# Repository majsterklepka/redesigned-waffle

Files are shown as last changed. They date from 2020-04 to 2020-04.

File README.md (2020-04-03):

# redesigned-waffle
mkII AVRISP programmer clone

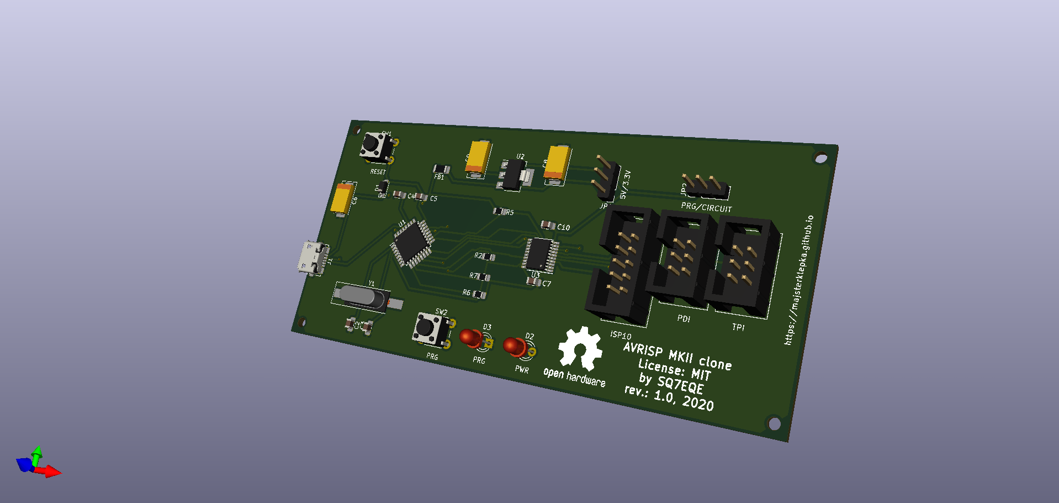
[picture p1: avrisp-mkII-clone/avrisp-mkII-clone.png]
PCB 3D view PCB Board 3D view


Projekt klonu wykonany w KiCad. Pewne elementy schematu ideowego wymagają bibliotek, są one dostępne tu: [majsterklepka/expert-waffle](https://github.com/majsterklepka/expert-waffle "eeschema KiCad Libraries"), należy sklonować repo i zainstalować wymagane biblioteki ręcznie.

Klon wykorzystuje framework [LUFA](https://github.com/abcminiuser/lufa "LUFA")

Schemat ideowy => [diagram](/avrisp-mkII-clone/avrisp-mkII-clone.pdf "diagram")

> **2020.04.02**   Dodałem pliki Gerber z rysunkiem płytki drukowanej

## Jak wgrać firmware?

Oczywiście, najpier należy je zdbudować, potem do wgrania firmware wykorzystuje się narzędzie `dfu-util` dostępne chyba w każdej dystrybucji Linuksa i xxxBSD.

## Jak wgrać firmware?

```
dfu-util --upload firmware.hex

gdzie:
firmware.hex - plik HEX z firmware, LUFA/Projects/AVRISP-MKII/

```

Tyle w skrócie, czasem należy podać dodatkowe dane, takie jak `<vendor>:<product>`. Te dane podaje się z opcją `--device`, więcej informacji:

```
dfu-util --help
```

## Credits

Jako taki projekt jest znany w Sieci, istnieje wiele dostępnych modyfikacji, tu jest jedna z nich.

- [MIT](https://raw.githubusercontent.com/majsterklepka/redesigned-waffle/master/LICENSE "MIT License content")

Ten projekt to moja wersja, moja wizja tego popularnego programatora.

_MSc. Paweł Sobótka (SQ7EQE)_

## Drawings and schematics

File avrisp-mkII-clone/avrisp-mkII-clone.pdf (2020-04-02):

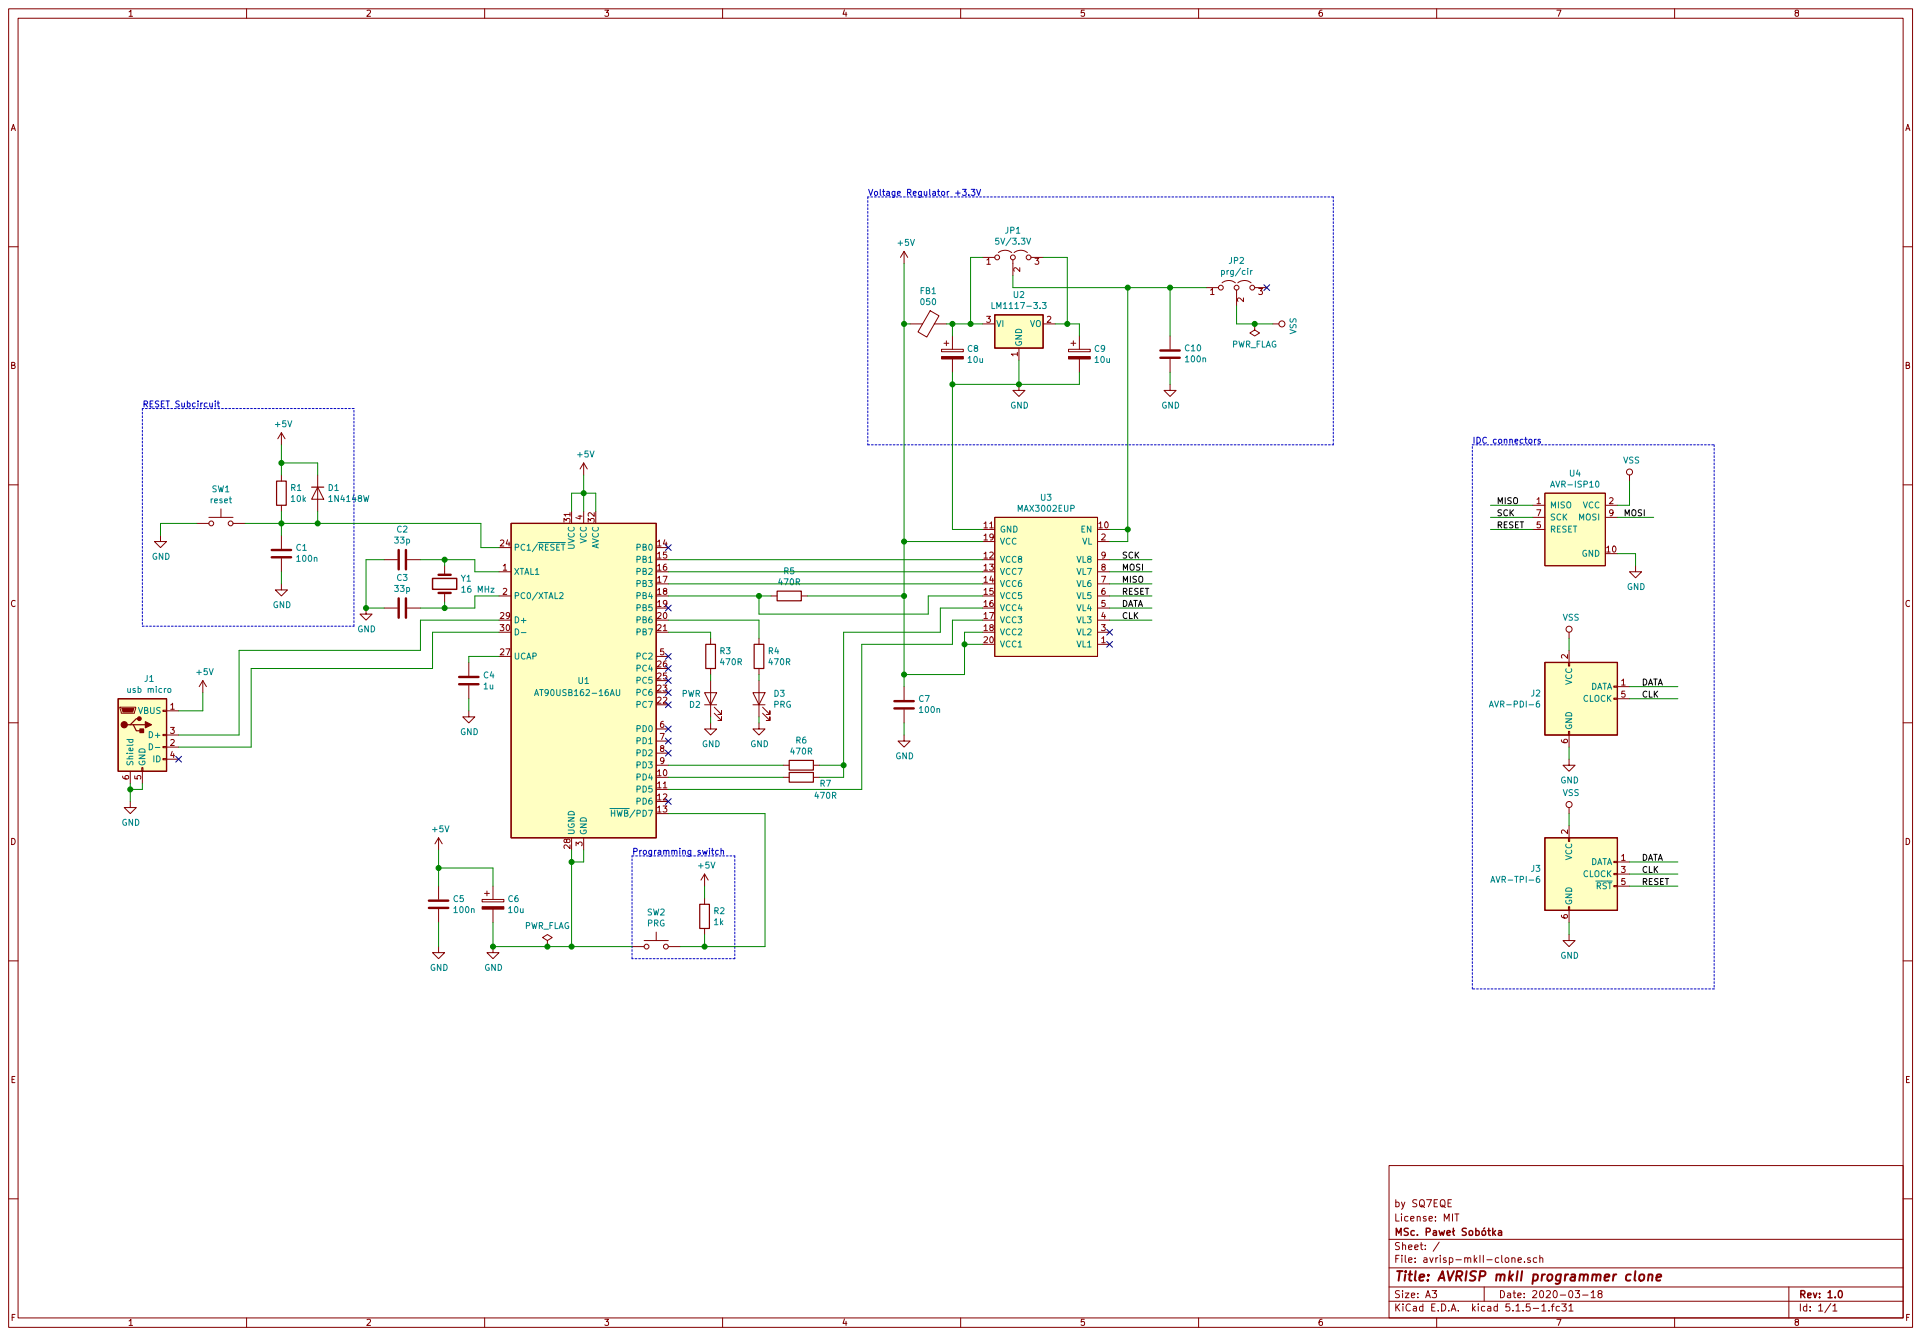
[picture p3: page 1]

IDC connectors Programming switch

by SQ7EQE
License: MIT
File: avrisp-mkII-clone.sch Sheet: / MSc. Pawe Sobótka

Id: 1/1 Title: AVRISP mkII programmer clone

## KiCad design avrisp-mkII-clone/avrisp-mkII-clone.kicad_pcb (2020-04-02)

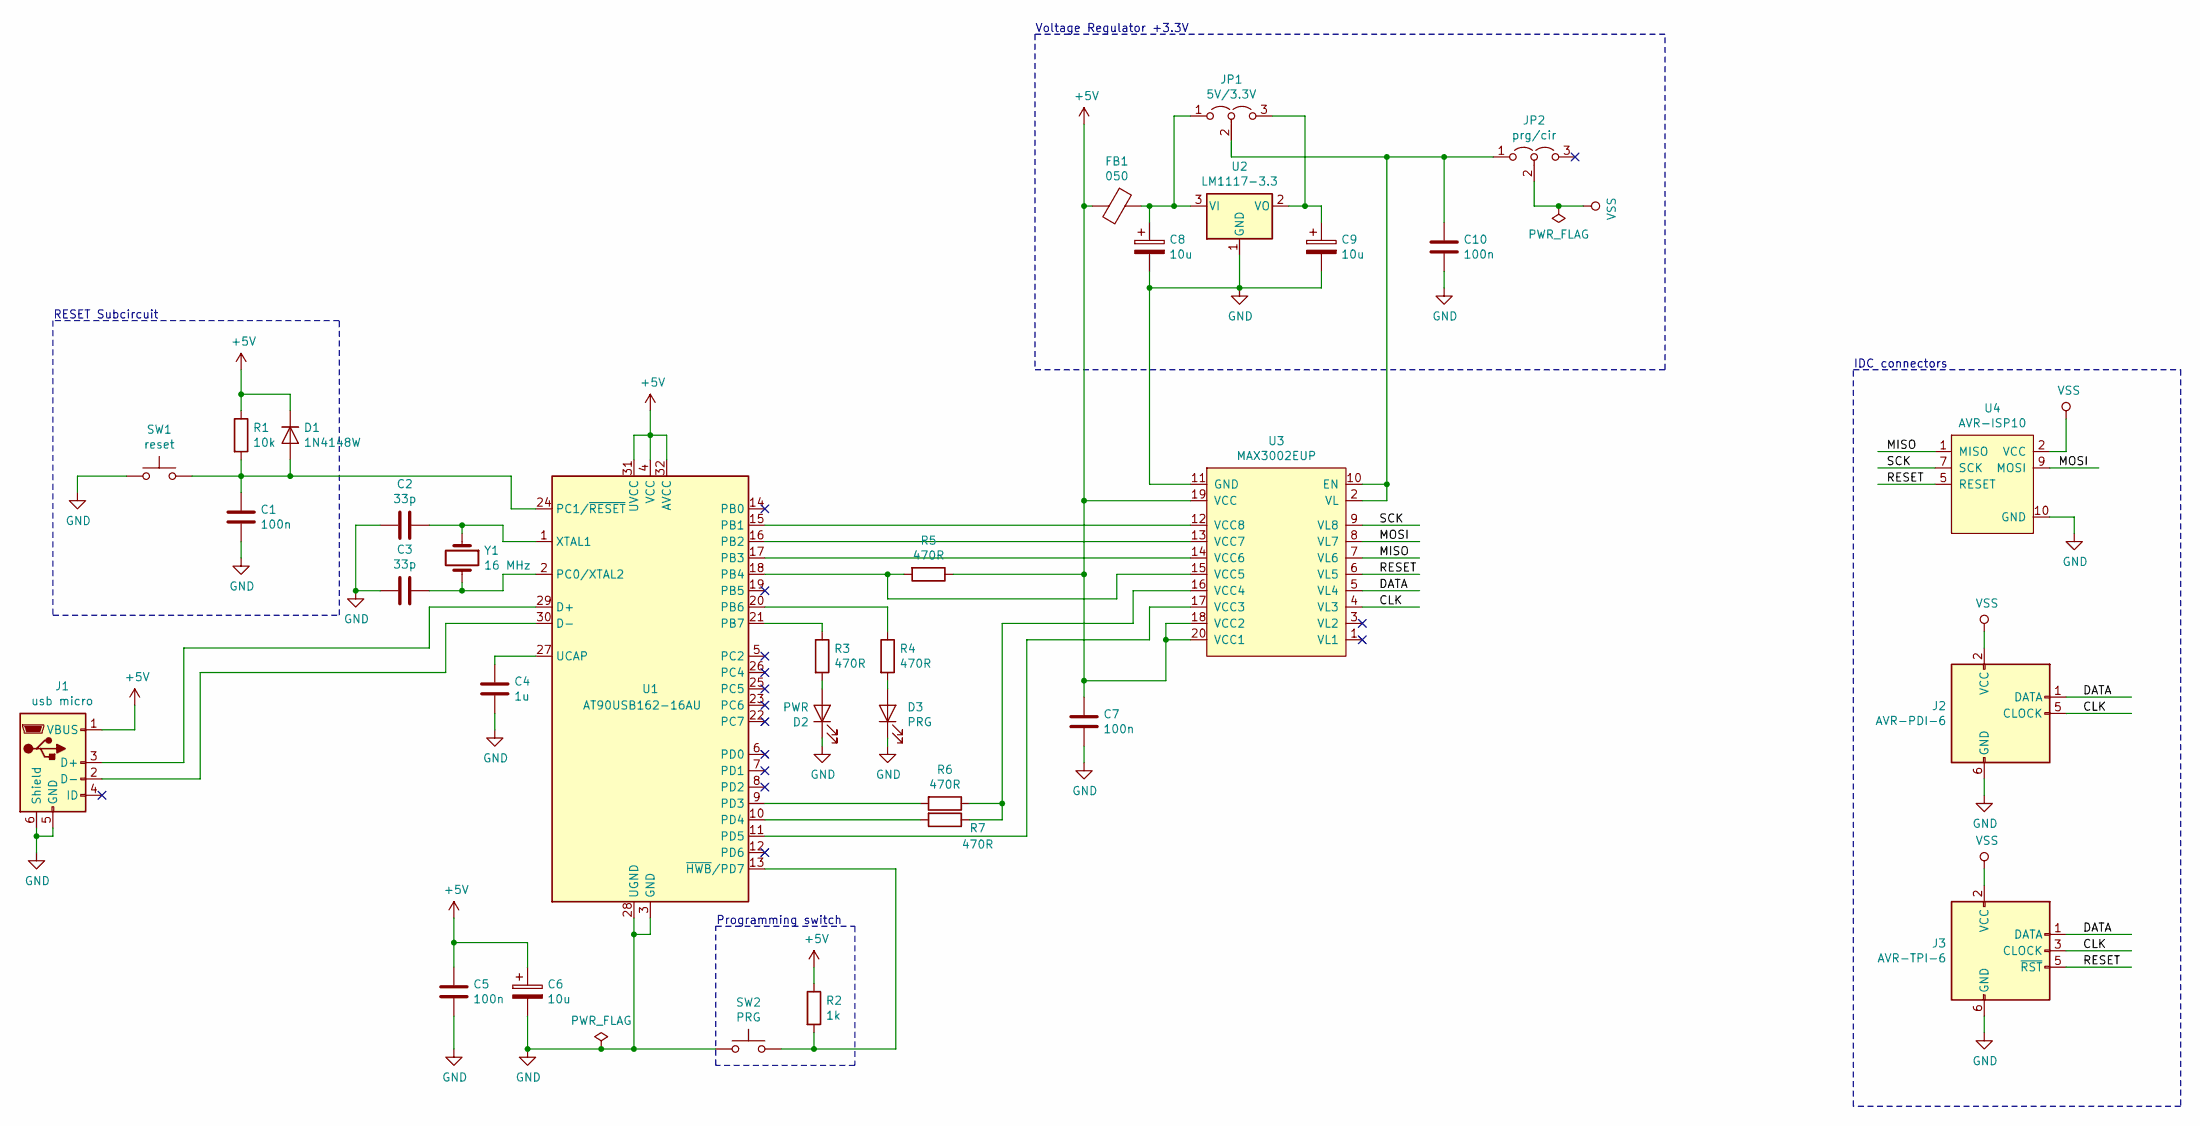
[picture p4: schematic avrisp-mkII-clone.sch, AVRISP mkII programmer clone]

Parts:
C1, C5, C7, C10: 100n; C_0805_2012Metric_Pad1.15x1.40mm_HandSolder
C2, C3: 33p; C_0805_2012Metric_Pad1.15x1.40mm_HandSolder
C4: 1u; C_0805_2012Metric_Pad1.15x1.40mm_HandSolder
C6, C8, C9: 10u; CP_EIA-7343-15_Kemet-W_Pad2.25x2.55mm_HandSolder
D1: 1N4148W; D_SOD-123
D2: PWR; LED_D3.0mm
D3: PRG; LED_D3.0mm
FB1: 050; R_1206_3216Metric_Pad1.42x1.75mm_HandSolder
J1: usb micro; USB_Micro-B_Molex_47346-0001
J2: AVR-PDI-6; IDC-Header_2x03_P2.54mm_Vertical
J3: AVR-TPI-6; IDC-Header_2x03_P2.54mm_Vertical
JP1: 5V/3.3V; PinHeader_1x03_P2.54mm_Vertical
JP2: prg/cir; PinHeader_1x03_P2.54mm_Vertical
R1: 10k; R_0805_2012Metric_Pad1.15x1.40mm_HandSolder
R2: 1k; R_0805_2012Metric_Pad1.15x1.40mm_HandSolder
R3, R4, R5, R6, R7: 470R; R_0805_2012Metric_Pad1.15x1.40mm_HandSolder
SW1: reset; SW_PUSH_6mm_H5mm
SW2: PRG; SW_PUSH_6mm_H5mm
U1: AT90USB162-16AU; TQFP-32_7x7mm_P0.8mm
U2: LM1117-3.3; SOT-223
U3: MAX3002EUP; TSSOP-20_4.4x6.5mm_P0.65mm
U4: AVR-ISP10; IDC-Header_2x05_P2.54mm_Vertical
Y1: 16 MHz; Crystal_SMD_HC49-SD_HandSoldering

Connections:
+5V: C5.1, C6.1, C7.2, D1.1 (K), FB1.2, J1.1 (VBUS), R1.1, R2.1, R5.1, U1.4 (VCC), U1.31 (UVCC), U1.32 (AVCC), U3.18 (VCC2), U3.19 (VCC), U3.20 (VCC1)
/CLK: J2.5 (CLOCK), J3.3 (CLOCK), U3.4 (VL3)
/DATA: J2.1 (DATA), J3.1 (DATA), U3.5 (VL4)
/MISO: U3.7 (VL6), U4.1 (MISO)
/MOSI: U3.8 (VL7), U4.9 (MOSI)
/RESET: J3.5 (~RST), U3.6 (VL5), U4.5 (RESET)
/SCK: U3.9 (VL8), U4.7 (SCK)
GND: C1.1, C2.2, C3.2, C4.2, C5.2, C6.2, C7.1, C8.2, C9.2, C10.1, D2.1 (K), D3.1 (K), J1.5 (GND), J1.6 (Shield), J2.6 (GND), J3.6 (GND), SW1.1, SW2.1, U1.3 (GND), U1.28 (UGND), U2.1 (GND), U3.11 (GND), U4.10 (GND)
unnamed: C1.2, D1.2 (A), R1.2, SW1.2, U1.24 (PC1/~RESET)
unnamed: C2.1, U1.1 (XTAL1), Y1.1
unnamed: C3.1, U1.2 (PC0/XTAL2), Y1.2
unnamed: C4.1, U1.27 (UCAP)
unnamed: C8.1, FB1.1, JP1.1 (A), U2.3 (VI)
unnamed: C9.1, JP1.3 (B), U2.2 (VO)
unnamed: C10.2, JP1.2 (C), JP2.1 (A), U3.2 (VL), U3.10 (EN)
unnamed: D2.2 (A), R3.2
unnamed: D3.2 (A), R4.2
unnamed: J1.2 (D-), U1.30 (D-)
unnamed: J1.3 (D+), U1.29 (D+)
unnamed: R2.2, SW2.2, U1.13 (~HWB~/PD7)
unnamed: R3.1, U1.21 (PB7)
unnamed: R4.1, U1.20 (PB6)
unnamed: R5.2, U1.18 (PB4), U3.15 (VCC5)
unnamed: R6.1, R7.1, U3.16 (VCC4)
unnamed: R6.2, U1.9 (PD3)
unnamed: R7.2, U1.10 (PD4)
unnamed: U1.11 (PD5), U3.17 (VCC3)
unnamed: U1.15 (PB1), U3.12 (VCC8)
unnamed: U1.16 (PB2), U3.13 (VCC7)
unnamed: U1.17 (PB3), U3.14 (VCC6)
VSS: J2.2 (VCC), J3.2 (VCC), JP2.2 (C), U4.2 (VCC)

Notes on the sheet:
RESET Subcircuit
Voltage Regulator +3.3V
IDC connectors
Programming switch

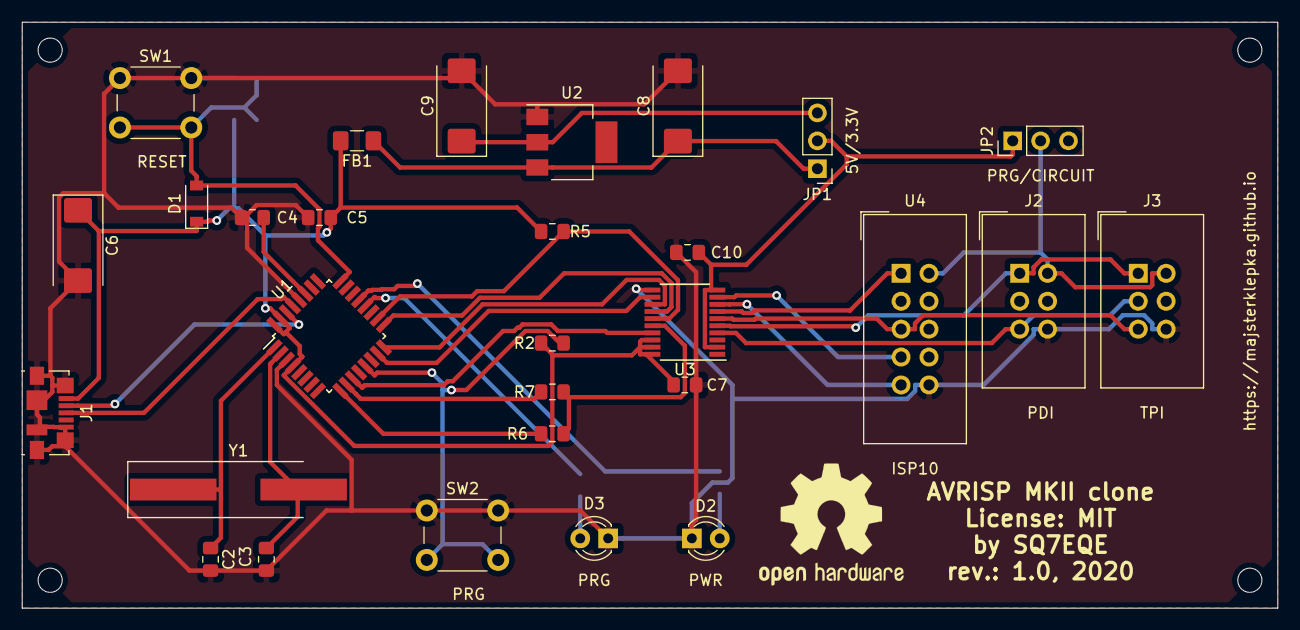
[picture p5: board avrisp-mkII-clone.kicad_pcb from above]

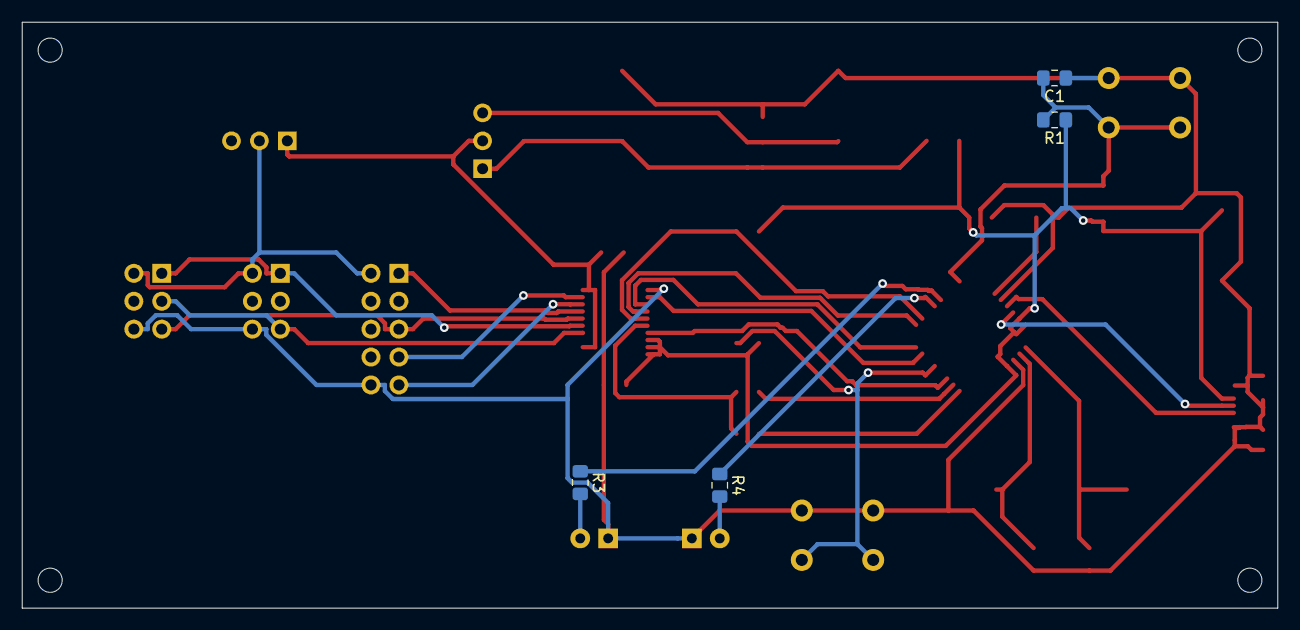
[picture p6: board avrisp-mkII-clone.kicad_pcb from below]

Board: 2 copper layers, 114.3 x 53.3 mm, 37 parts (4 on the bottom side), 31 nets.

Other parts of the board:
M1, M2, M3, M4: MountingHole_2.2mm_M2_DIN965

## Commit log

2020-03-24 new file
    [avrisp-mkII-clone.kicad_pcb, avrisp-mkII-clone.sch]
2020-04-02 add Gerber file
    [avrisp-mkII-clone-B_Adhes.gbr, avrisp-mkII-clone-B_CrtYd.gbr, avrisp-mkII-clone-B_Cu.gbr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]
2020-04-02 update project file
    [avrisp-mkII-clone.dsn, avrisp-mkII-clone.kicad_pcb, avrisp-mkII-clone.sch]
